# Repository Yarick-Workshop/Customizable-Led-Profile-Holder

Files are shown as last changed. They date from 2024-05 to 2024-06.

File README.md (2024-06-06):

Shield: [][cc-by-nc-sa]
<!-- Thanks to this Guy: https://github.com/santisoler/cc-licenses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>
This work is licensed under a
[Creative Commons Attribution-NonCommercial-ShareAlike 4.0 International License][cc-by-nc-sa].

[][cc-by-nc-sa]

[cc-by-nc-sa]: http://creativecommons.org/licenses/by-nc-sa/4.0/
[cc-by-nc-sa-image]: https://licensebuttons.net/l/by-nc-sa/4.0/88x31.png
[cc-by-nc-sa-shield]: https://img.shields.io/badge/License-CC%20BY--NC--SA%204.0-lightgrey.svg

# LED profile holder "Scorpion"

<p align="center" width="100%">
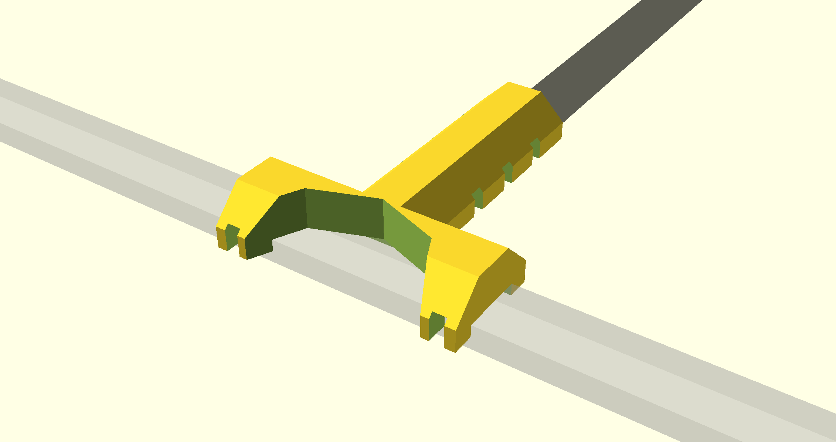
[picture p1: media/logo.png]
    
</p>

The model was designed for producing on a 3D printer.

⚠️ **In case of any questions** – do not hesitate to contact the author in Telegram group ([see below](#contact-me)) and ask.

## HOWTO

⚠️ Before assembling read the topic to the bottom!

This 3D model is highly customizable. So you can configure it for you needs.

### Pre-rendered STL

If you do not need any customizations and would only like to have the same holder as I have – you can download prerendered STL file from Thingiverse:

  * https://www.thingiverse.com/thing:6643654

### Model Parameters

I used self-explanatory names for OpenSCAD model parameters. But if you still have any questions – [contact me](#contact-me).

### Print Settings

Here is an example of my **printing parameters**:

|Name|Value|Comment|
|--|--|--|
|Nozzle diameter|0.4 mm|0.5, 0.6 and even 1 mm could could also be fine. Try!|
|Layer height/First layer height|0.2 mm||
|Perimeters|3||
|Solid layers - top/bottom|6||
|Fill density|25%|15% should be enough|
|Fill pattern|Cubic||
|Supports|Not needed|The model was designed to be printed without any supports|
|Filament|CoPET(PETG)|ABS would be better because of the profile heating)|

It is just an example. So you can play with yours 🙂. 

It took me a bit more than 2 hours to print on my Graber i3 printer. Printing time depends on kind on printer and the printing parameters. 

### Assembling

To assemble the a LED lamp or a fito-lamp you will need the next **Tools and Materials**: 

|Name|Quantity|Comment|
|--|--|--|
|LED profile|||
|LED strip||Or a FITO-LED strip as in my case|
|LED diffuser|||
|Zip tie 3.6mm x 200mm|5|They are used as fasteners.  Model is customizable so it is possible to configure for other size of zip ties|
|Power Supply 12 or 9 V, 2A|1|12 V led to overheating LED-profile and as result to hypothetical melting of plastic parts. So I've chosen 9 V PS|
|Drill bit ⌀ 1.5 mm(?)|1|To drill holes for cables in a Cap|
|Cable|0.3 - 0.5 m||
|Power socket|1||
|Flexible phone holder|1|If you don’t have one, use a selfie stick or, alternatively, something else in the shape of a pipe will be fine too|
|Drill|1|Even a primitive one because it will be used for drilling plastic parts only|
|File|1||
|Metal cutting saw|1||
|Pliers|1|Or strong fingers to tighten zip ties 🙂|
|Side cutters|1||
|LED Profile Cap|2|You can either buy or print [Customizable LED-Profile Cap](https://github.com/Yarick-Workshop/Customizable-Tube-Cap)|
|Filament| ~25 g | **coPET (PETG)** is fine, but **ABS** is preferable. Because the LED-profile gets hot. **PLA** - I think not a suitable option for the same reason|
|3D printer|1| Or a friend with a 3D printer 😉|

⚠️ If you have everything from the table above **follow the next assembling video manual**: https://youtu.be/041HFlZdGfg

*Yeah, the video is in Russian but there are English subtitles too. I tried to do my best translating them to English. But if you see something could be fixed - [let me know](#contact-me) please and I will update the text. The same for text here as well. Thank you in advance!*

## Contact me

To follow the progress go to my channels:
  - Telegram: [https://t.me/YarickWorkshop](https://t.me/YarickWorkshop/316)
  - YouTube: https://www.youtube.com/@yarick-workshop

Yeah, they both are in Russian.

**If you have any questions** – contact me in either Telegram channel (see above) or Mail: techno.man.983@gmail.com. I can communicate in English without any problems. 

⚠️ **Pay attention**: I do not answer to any comments on YouTube (despite I read them). Why? It is a HUGE secret 🙃

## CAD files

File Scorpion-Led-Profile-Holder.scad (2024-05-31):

/* [Generic] */
min_Wall_Thikness = 4;
cable_Tie_Cave_Width = 4;

/* [Handle] */
handler_Length = 60;
handler_Internal_Diameter = 14;
handler_Tie_Cave_Offset = 15;
handler_Ball_Diameter = 17.5;

/* [Profile holder]  */ 
led_Holder_Length = 70;
led_Holder_Tie_Cave_Offset = 5;
led_Profile_Heigh = 7;
led_Profile_Width = 18;

/* [Hidden] */
//to hide artefacts
delta = 0.01;

handler_External_Diameter = max(handler_Internal_Diameter, handler_Ball_Diameter) + 2 * min_Wall_Thikness;
led_Holder_External_Diameter = sqrt(led_Profile_Heigh * led_Profile_Heigh + 
            led_Profile_Width * led_Profile_Width / 4) * 2 
            + 2 * min_Wall_Thikness;

// SEE  undersized holes here: 
// https://en.wikibooks.org/wiki/OpenSCAD_User_Manual/The_OpenSCAD_Language#cylinder
// to understan why
handler_External_Diameter_Fixed = handler_External_Diameter / cos(180 / 8);
led_Holder_External_Diameter_Fixed = led_Holder_External_Diameter / cos(180 / 8);

holder();

module holder()
{
    handler();

    translate([0, (handler_Length + led_Holder_External_Diameter) * 0.5, 0])
        rotate([0, 0, 90])
            led_holder();
}
        
module handler()
{
    translate([0, 0, handler_External_Diameter * 0.5])
        rotate([90, 0, 0])
            difference()
            {
                workpiece_with_tie_cave(diameter = handler_External_Diameter,
                    diameter_fixed = handler_External_Diameter_Fixed,
                    height = handler_Length,
                    cave_offset = handler_Tie_Cave_Offset);
                
                // groove
                cylinder(h = handler_Length + delta, d = handler_Internal_Diameter, center=true, $fn=360);
                
                cutter(handler_External_Diameter);

                translate([0, 0, -(handler_Length - handler_Ball_Diameter) * 0.5])
                    sphere(d=handler_Ball_Diameter, $fn=360);
            }
}

module led_holder()
{
    translate([0, 0, led_Holder_External_Diameter * 0.5])
        rotate([90, 0, 0])
            difference()
            {
                union()
                {
                    workpiece_with_tie_cave(diameter = led_Holder_External_Diameter,
                        diameter_fixed = led_Holder_External_Diameter_Fixed,
                        height =led_Holder_Length,
                        cave_offset =led_Holder_Tie_Cave_Offset);
                    rotate([0, 90, 0])
                        translate([0, (handler_External_Diameter - led_Holder_External_Diameter) * 0.5, -led_Holder_External_Diameter * 0.25 - delta])
                            workpiece(diameter = handler_External_Diameter,
                                diameter_fixed = handler_External_Diameter_Fixed,
                                  height = led_Holder_External_Diameter * 0.5);
                }
                
                // a groove for sinking the heat from the LED profile
                // To sink just in the half to the holder translate([0, -led_Profile_Heigh * 0.5, 0])
                cube([led_Profile_Width, led_Profile_Heigh, led_Holder_Length + delta], center=true);
                translate([led_Holder_External_Diameter_Fixed * 0.5, 0, 0])
                    rotate([90, 0, 0])
                        scale([led_Holder_External_Diameter_Fixed * 1.4, led_Holder_Length - 3.5 * led_Holder_Tie_Cave_Offset, ])
                            cylinder(h=led_Holder_External_Diameter_Fixed + delta, d=1, center=true, $fn=8);
            }
}
module workpiece_with_tie_cave(diameter, diameter_fixed, height, cave_offset)
{
    difference()
    {
        workpiece(diameter, diameter_fixed, height);
        
        // tie cave
        translate([0, 0, height * 0.5 - cave_offset])
            cutter(diameter);
        translate([0, 0, -height * 0.5 + cave_offset])
            cutter(diameter);
    }
}

module workpiece(diameter, diameter_fixed, height)
{
    //external figure 
    difference()
    {
        rotate([0, 0, 360 / 8 / 2])
            cylinder(h = height, d = diameter_fixed, center=true, $fn=8);
        
        // remove half of the figure
        translate([0, diameter * 0.5, 0])
            cube([diameter + delta, diameter, height + delta], center=true);
    }
}

module cutter(diameter)
{
    difference()
    {
        cube([diameter + delta, diameter + delta, cable_Tie_Cave_Width], center = true);
        translate([0, - diameter * 0.5, 0])
            rotate([0, 0, 45])
            cube([diameter, diameter, cable_Tie_Cave_Width + delta], center = true);
    }
}

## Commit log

2024-04-01 Increased led heatsink width
    [Scorpion-Led-Profile-Holder.scad]
2024-04-01 Different Diameters for Profile holder and the handle
    [Scorpion-Led-Profile-Holder.scad]
2024-04-01 Fixed wall thickness near the ball
    [Scorpion-Led-Profile-Holder.scad]
2024-04-01 Fixed typos and polished
    [Scorpion-Led-Profile-Holder.scad]
2024-04-02 Fixed wall thickness calculation
    [Scorpion-Led-Profile-Holder.scad]
2024-05-31 Refactored parameters and other polishings
    [Scorpion-Led-Profile-Holder.scad]
2024-06-06 Finished "Assembly" chapter

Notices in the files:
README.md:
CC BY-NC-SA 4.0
